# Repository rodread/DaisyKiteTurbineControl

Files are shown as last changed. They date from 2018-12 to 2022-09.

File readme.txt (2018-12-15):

This is the software Rod Read used to control his Daisy Kite turbine on 13/12/2018
The flying rigid rotor kite trubine output over 1kW so this is NO TOY and not for the faint of heart.
Wear a helmet and other protective gear. Stand far clear and not directly downwind or anywhere lashback will be a concern.

You can see just how insane this is here https://youtu.be/UpIECYxP4xc

I was too lazy to reinstate a previous push button for manual overdrive to take twists out... doh
I also aught to go back to having a manual current control for careful slowing down...

As you can see my code is about as far from optimal as a noob like me can mangle

Thanks
rod

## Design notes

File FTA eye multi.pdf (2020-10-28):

384

Ground Station Failure

262

Generation Failure

85
Lifter Fail

Turbine Failure

Transmission Failure

172

56

Material thrown from turbine

871

648

Anchoring error

165

613

75

Backline Fail

Generator Control Compromised

56

689
Generation compromised

248

Efficiency reduced

480

1150

153

Turbine wobble

Transmission compromised

Lift kite position Instability

176

Lift line tension low

Top Lift function fail

Turbine integrity compromised

195

70

147

Backline Safety removed

Rotor stall ability potentially gone

Twisting Lift line

Loss of spreader circular form

Blade integrity compromised

Lift Kite in low turbulent wind

177

105

70

Compression likely on turbine ring

515

Lift Kite in unauthorised airspace

60

Potential for blade strike

Wrong data to controller

Lift kite breakaway

PTO elevation alignment error

56

60

Data recording compromised

Fire risk

14

Ground station position not fixed

285

270

Compression likely on transmission

156

162.5

Thrust transfer to ring compromised

62

546

Battery damage

PTO azimuth alignment error

164

Chain compromised

13

56

32

High degree of twist in turbine form

Transmission centre point disk snags on lift line RPN=32

Ring connector tabs on rim wear out RPN=28

PTO Hub buckles RPN=24

PTO spoke and/or nipple thrown RPN=48

Stub axle thrust bearing circlip dislodged RPN=64

Thrust bearing wears out RPN=36

Stub axle rusts RPN=30

Stub axle weld snaps RPN=16

load cell connection breaks RPN=42 elevaiton arm conncetion breaks RPN=32 motor mount arm welds fail RPN=16 mount or chainring bolt fail RPN=36 magnet too far away RPN=18

Teeth Fatigue wear RPN=30

Chain snaps RPN=14

Sprocket tooth snaps RPN=24 motor/generator overheats from too much current RPN=42 motor/generator bearings wear out RPN=36 motor/genertor cable wiring fault develops RPN=72 elevation adjustment bars fall from nuts and mounts RPN=28 initial tension may not be calibrated at launch RPN=63 control board communicion with load cell system lost RPN=56 load cell cable wiring fault develops RPN=72

bolt unable to provide head movement in frame RPN=42

frame breaks RPN=16

motor alignment too far out RPN=36 head spreader bolt wrong width setting RPN=28

frame buckle RPN=24

stitching failure RPN=32

Sprocket teeth fatigue wear RPN=15

Tracking wheels seize RPN=28 all hub bolts snap or seperate RPN=18

Bridle Point detached from lift line RPN=5

chainring tooth snaps RPN=24

Lift line (Bridle point to back line connection) snap RPN=8

one hub bolt snaps or seperates RPN=32 wheel track blocked with vegitation RPN=42

Back line snap RPN=14

Main Anchor total failure RPN=36

Anchor bends RPN=48

Back anchor missalignment with wind RPN=70

Threaded eye bolt pulled off RPN=8

Back anchor leaves ground RPN=28

VESC not detecting motor/ generator parameters RPN=72

VESC not communicating with control board RPN=63

PTO wheel pulled from stub axle position RPN=48

Lift line snap below top bearing RPN=10

Water ingress into housing RPN=42

failure to read control knob states RPN=72

Transmission Centre point disk line snaps RPN=42 spreader ring rod connector snap RPN=30

spreader ring rod thrown from ring RPN=48 software written by a neewbie RPN=72 control board not communicating with anemometer RPN=42

Top lifting bridle snaps RPN=63 control board not communicating with PC RPN=18

Top Spreader ring centre point disk jams on lift line RPN=21

anemometer failure RPN=28

Fuselage Blade Cuff snap RPN=96

Fuselage body (ring tube) snap RPN=72 wrong speed reading reported from board after voltage change RPN=63 large current spikes on switching RPN=63

Foam blade deterioration RPN=60 electrical power measuring failure RPN=42

large arking current on connection RPN=42

blade cover film deterioration RPN=18

blade cover film detachment RPN=32

Carbon spar tube thrown from blade RPN=32

Through spar retaining line snaps RPN=28

Through spar retaining line thrown RPN=28

Foam Blade Bridle snaps RPN=72

Blade bridle topside spreader thrown RPN=36

Fuselage Bonding Tape tears RPN=36

Carbon spar tube snap RPN=96

Ring tube cuff clasp opens RPN=84

Ring tube cuff tears RPN=54

Foam blade thrown from fuselage RPN=48

Blade position inversion RPN=56

Ring tube cuff line tab tears from cuff RPN=24

Foam blade snap RPN=48

Fuselage looses forward blade connection RPN=42

Fuselage looses trailing blade connection RPN=42

Ring tube snaps RPN=72

Ring tube thrown from turbine RPN=96

Ring Tube Center point disk line snaps RPN=36

Top Spreader ring centre point lines disconnect RPN=24

Turbine ring Center point disk snags on lift line RPN=21 spreader sleeve opens RPN=30 spreader tab disconnects RPN=10 spreader ring rod snap RPN=50

Tether line attachment rings wear or yeild to tension stress RPN=48 Tethers between turbine rings snap RPN=48

Lift line tension too tight inside turbine RPN=87.5

Lift line tension too loose inside turbine RPN=48

Tethers between turbine layers twist RPN=72

Lift line abrasion snap above or in top bearing RPN=72

Lifting bridle detach from small wheel RPN=30

Bearing seizure or high friction RPN=20

Tethers between transmission rings snap RPN=48 | Tethers between transmission rings twist RPN=96

Back anchor connector snap RPN=14

Back line tension too low RPN=40

Transmission ring rod snaps RPN=84 low lift line tension RPN=75

Lift line Length above back line too short RPN=32

Lift line Length above back line too long RPN=56

Transmission ring rod thrown RPN=48

Transmission cuff tears RPN=63

uneven stretch RPN=27

Bridle snap RPN=24

Transmission tabs separate from cuff RPN=14

Lift kite alignment error RPN=40

Skin tear RPN=30

Transmision end connectors separate RPN=28

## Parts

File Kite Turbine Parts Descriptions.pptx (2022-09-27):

## Sub 1kW Kite Turbine Parts

The following parts descriptions are relevant to the <1kW mechanically autonomous Kite Turbines developed at Windswept and Interesting Ltd.
These details are released CC-BY-SA-4.0
TRL ratings are given in the context of a fully autonomous product safe enough to release to the general public as a product.
This turbine design - is not a safe product. You would only replicate this assuming all risk and responsibility

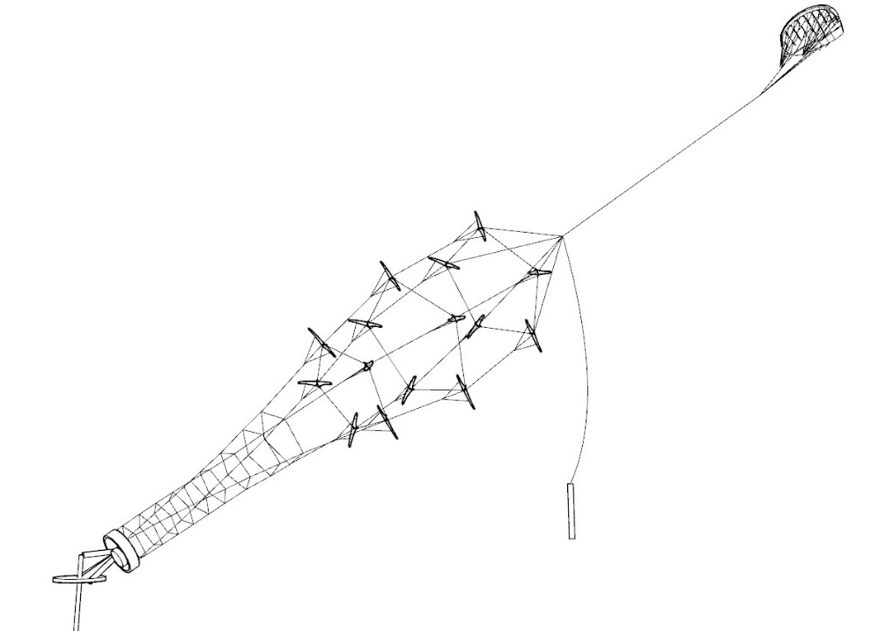
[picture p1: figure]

Lift Kite

Turbine Head

Turbine

Transmission

Backline Handling

Ground Station

## Kite Turbine sub-systems

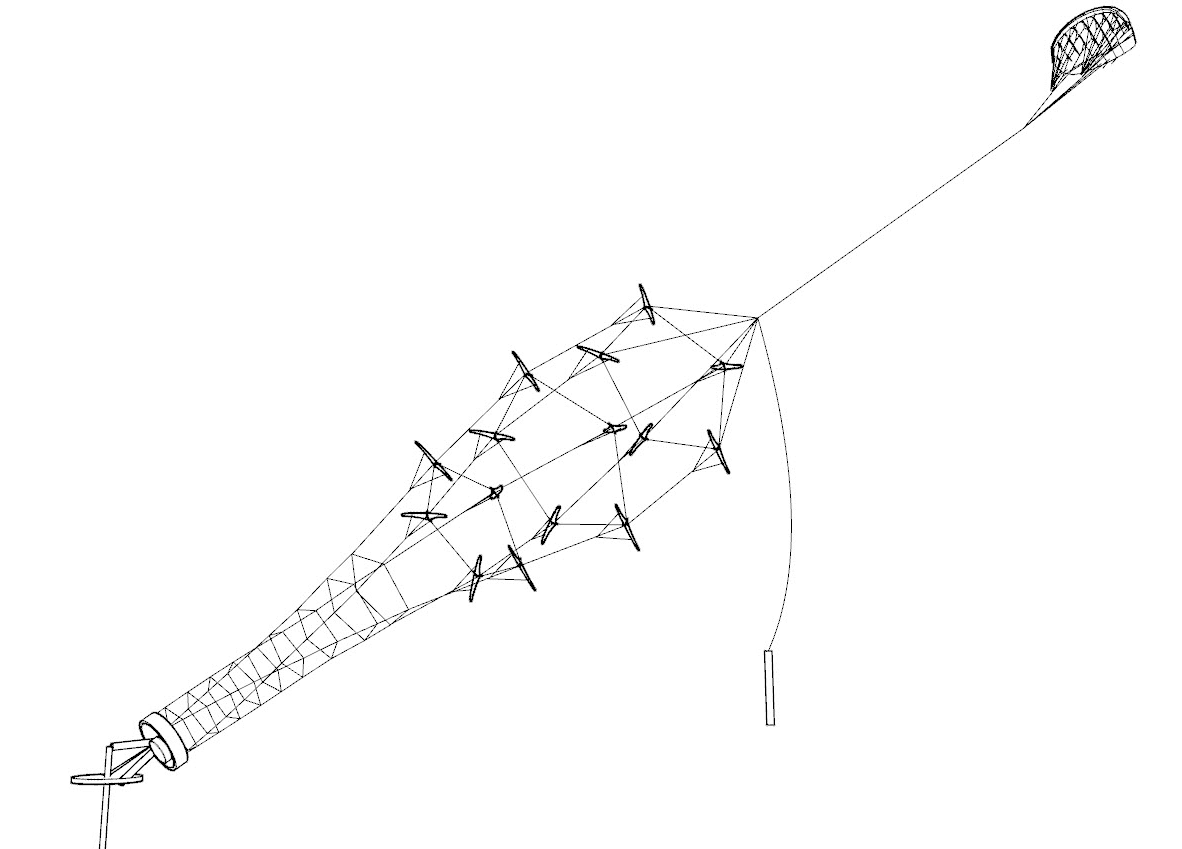
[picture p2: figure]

Lift Kite

Turbine Head

Turbine

Transmission

Backline Handling

Ground Station

## Lift Kite

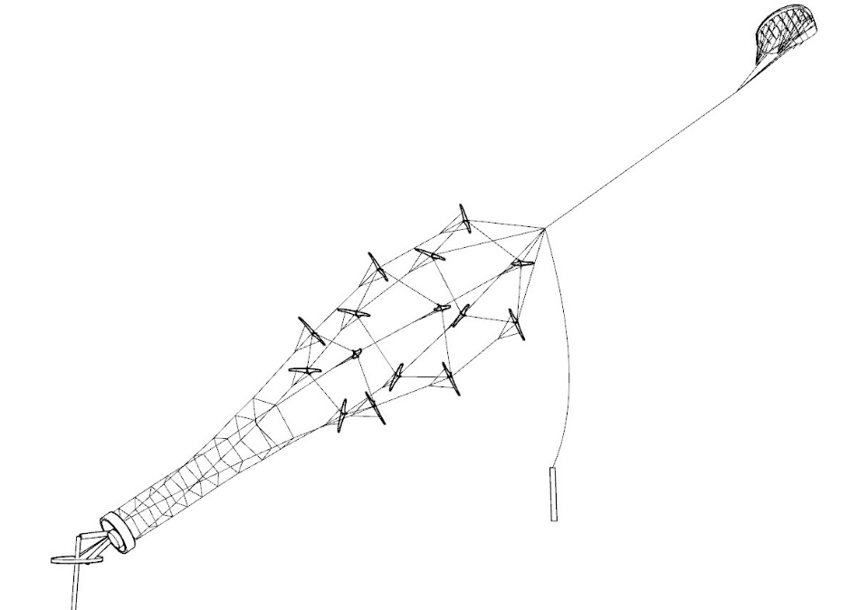
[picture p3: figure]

Lift Kite

Turbine Head

Turbine

Transmission

Ground Station

Backline Handling

State TRL 3 Some basic concept prototypes and models have had an initial field trial Others are still only conceptual. Analogous products exist elsewhere in AWES.

The Lift Kite was always hand launched and landed. - Automating this functionality may help your project.
The Lift kite was mostly a mechanically autonomous HQ KAP lift foil. - Automating this may help your project.
Short tests of battery powered RC servo bridle winding steering systems had run successfully.
You might consider a flight controller, onboard charging, communications, rtk GPS and novel steering.
Steering has run on basic IMU sensing with bluetooth control - You will want to update steering algorithms, Add field wifi and operational mode awareness for reliability and safety.
Lift Kite position was occasionally limited within the prevailing wind with two additional lightweight steering anchor lines tied to steering bridles - You may want to address methods of full azimuth operation and bank angle control to enable operation throughout the wind window and in changing wind conditions.

Windswept & Interesting Ltd, Emsket, Nesbister, Shetland ZE2 9LJ Registered Limited Company SC439249

## Turbine Head

State TRL 3
The turbine head has been constructed from adapted skate wheel and axle configurations. No smarts included.
The system has run both ways - with simple through axles holding the turbine tip whilst the rim held the top lift line steady and with the turbine on the rim and the axle steadied by the lift and backline. This second configuration is preferred.
No attitude, speed, power, monitoring, communications, control or autonomous connection has yet been functionally implemented

You may want to augment a turbine head to be capable of communicating rtk gps position and line tension data to aid ground station alignment and backline handling. The turbine head is attached and detached from the lift-line/ back-line whilst in the launch and land stages.

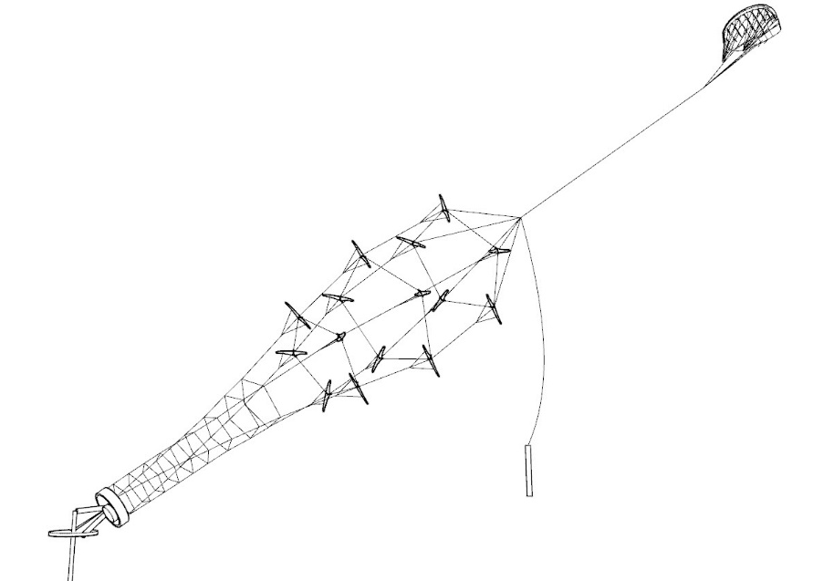
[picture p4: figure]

Turbine Head

Lift Kite

Turbine

Transmission

Ground Station

Backline Handling

## Backline Handling

State TRL 3
The Backline Handling has been limited to manual handling operations to date.
The backline has been a partially bungeed line, anchored to hold the turbine head lower and downwind.
On occasion we used spread twin lines from the ground to the turbine head & lift line connection point - to limit azimuth drift under an unsteady lifter.
A straight line ground “horsetrack” backline anchor system has been trialled to allow azimuth tracking whilst keeping backline tension.
The backline has been tested with bungee to remove the potential for slack to wrap around in the case of torque transfer to the lift line.
The backline has been manually tested for turbine stalling. In turbine stalling the backline is pulled around the field to pull the turbine head to a position 90 deg to the inflow of wind… Thus stalling the turbine.

Lift Kite

Turbine Head

Transmission

Ground Station

Turbine

Backline Handling

## Turbine

State TRL 4
Several “blade” kites set around a rigidised ring form a turbine rotor.
Our early turbines mostly exploited the cheap and easy fix nature of ram air kites attached to varied forms of ring support system.
A shift in design to rigidised foam profile wings resulted in the best AWES Power/Weight test efficiency to date.
A first description of the turbine system performance was achieved through a PhD collaboration with University of Strathclyde.

Turbine can be modularly constructed to be able to be flown alone or stacked together.
A turbine rotor can connect to another lower turbine rotor, or to the transmission.

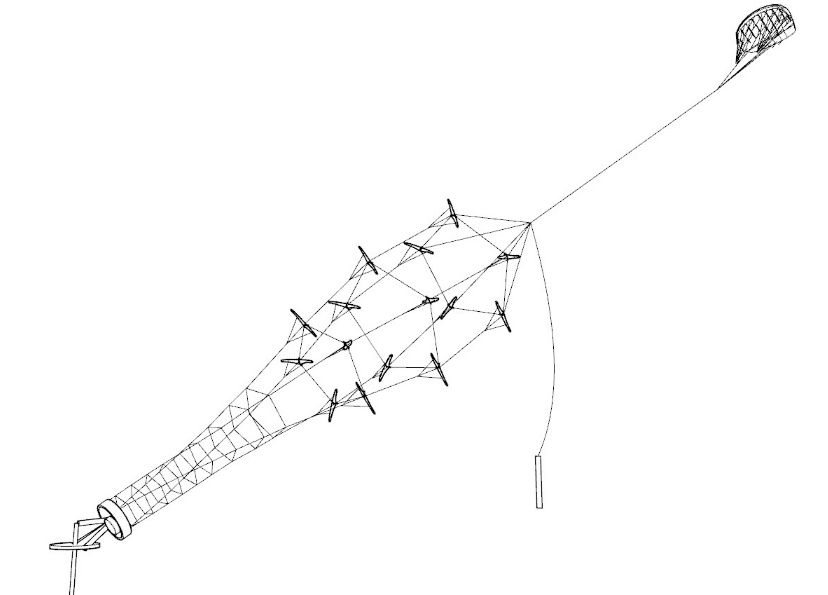
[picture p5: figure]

Lift Kite

Turbine Head

Turbine

Transmission

Ground Station

Backline Handling

## Transmission

State TRL 4
The unique dynamic properties of Tensile Rotary Power Transmission (TRPT) were described in Oliver Tulloch’s PhD.
TRPT is a new class of Airborne Wind Energy power transmission.
Several variations of transmission have been tested and characterised at W&I.
W&I prefer the more dynamic polygon to polygon TRPT in preference to rod to crossed rod style TRPT (see tuddel power someawe.org) due to handling and efficiency benefits

TRPT can be modularly constructed.
Transmission line tabs attach transmission lines to the polygon nodes.

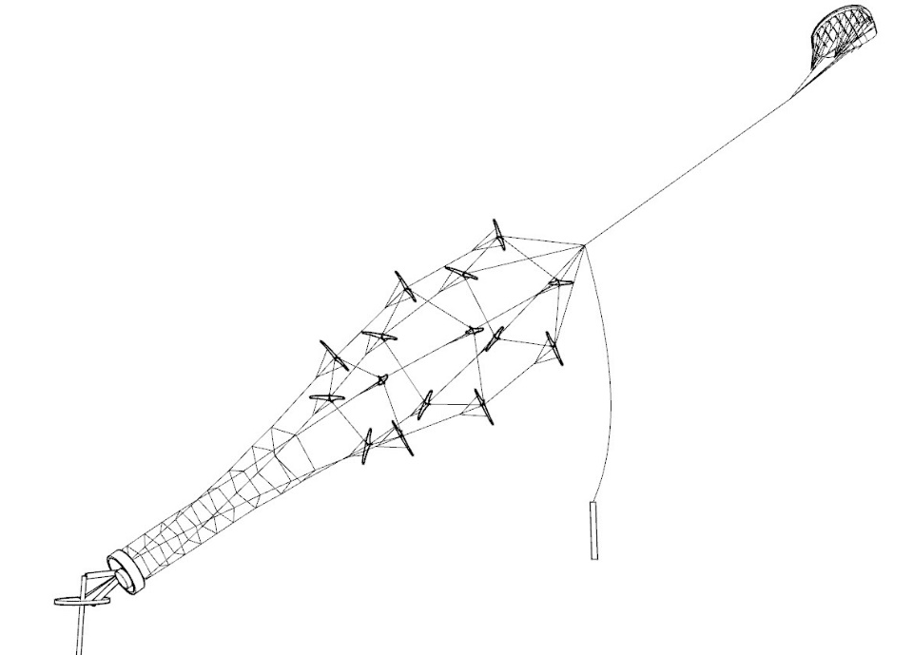
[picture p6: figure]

Lift Kite

Turbine Head

Turbine

Transmission

Ground Station

Backline Handling

## Ground Station

State TRL 3
The Ground Stations had passive azimuth alignment with elevation tracking predominantly being set pre-flight, manually. It is best to set this firmly before launch as the dynamic interaction of generation can easily impact axial alignment. This assumes you will hold the turbine head in a relatively fixed position.
The generation system used a VESC for torque control using FOC on a 500W rated BLDC motor. Regen went into 2 x e-bike batteries
Control commands came from a basic human interface combined in an algorithm with data from anemometer, onboard tension sensing and the speed controller.
Make sure your ground station is securely fixed to a very oversized anchor system.

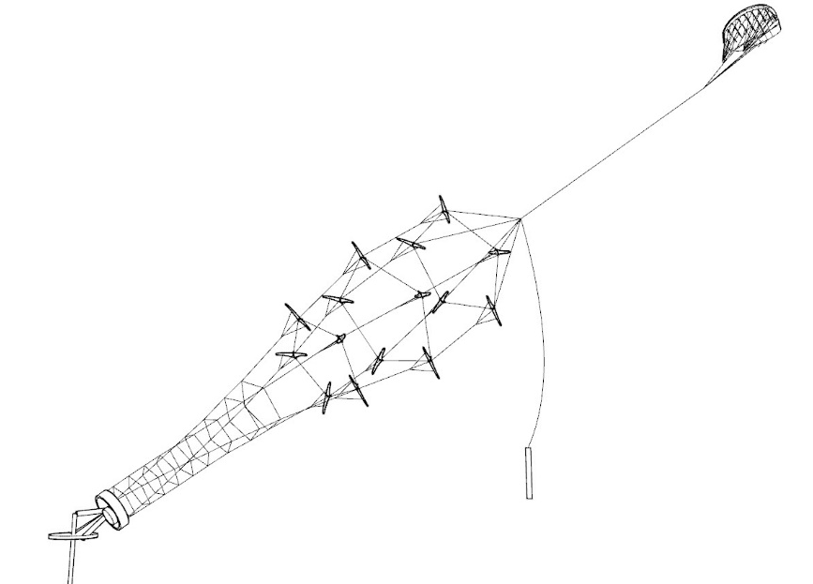
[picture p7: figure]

Lift Kite

Turbine Head

Turbine

Transmission

Ground Station

Backline Handling

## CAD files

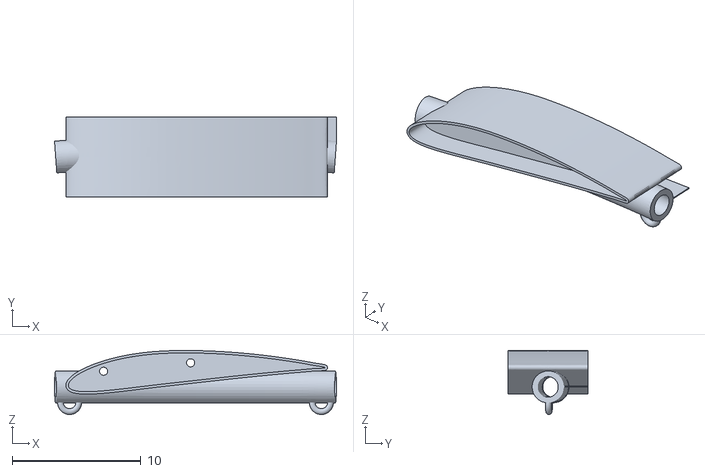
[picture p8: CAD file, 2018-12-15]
Cuff-thinner-foamCORE.stl
21.9 x 6.20 x 4.98

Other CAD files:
foamCOREdaisyDRIVERroot4.3dm

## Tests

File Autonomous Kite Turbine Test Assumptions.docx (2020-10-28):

# Autonomous kite network systems

# Assumptions on Proposals

### Proposals

The following models describe 4 Kite Turbine system configurations. The systems require increasing levels of development and autonomy for safe operation.

We describe 5 levels of autonomy (end of this document) which Kite Turbines and Lifting Kite Networks will employ. The simplest, level 1, mechanical autonomy with human interaction, has been well tested.

### Background

Windswept and Interesting developed a series of mechanically autonomous kite turbines. University of Strathclyde analysed the performance of 9 rotor configurations, over 120 hours of flight & 45 test flights. Over the test period the efficiency and power output of our turbines increased 10X. (Power harvesting factor ζ is now around 3.) Our Kite Turbines have the safest configuration & the best AWES Power/Weight & Power/Wing Area. This is the only AWES with continuous rotary output.

A lightweight tensile design, exploiting network deployment, makes Kite Turbines very scalable.

Kite Turbine power coefficients have stayed constant with stacking. We predict the following performance benefits with network scaling … decreased drag, maximised utility of harvested airspace, robust operation, mass production with unitised wing components, modular reconfiguration while flying & in deployment, networked form safety and more.

This is the first predictive LCOE analysis by W&I on our systems at scales over 10kW. W&I have no prior experience of manufacturing Kite Turbine products at this scale. There will be a lot of scope for production efficiency as compared to the costings shared here.

### Scale choices

The 4 systems presented are

### Model Proposal 1 10kW Kite Turbine with single lifter Level 3 Autonomy

### Model Proposal 2 50kW Kite Turbine with single lifter Level 4 Autonomy

### Model Proposal 3 1.8MW 18 lift kite network x 100kW kite turbines Level 4 Autonomy

### Model Proposal 4 10MW Single Kite Turbine Network no lifter Level 5 Autonomy

Models 1 & 2 represent the lower end scale of viable turbine size for their autonomy level. Larger, more profitable systems at the same level of autonomy would be possible and likely desirable.

### Model Proposal 1

## 10kW Kite Turbine with single lifter Level 3 Autonomy

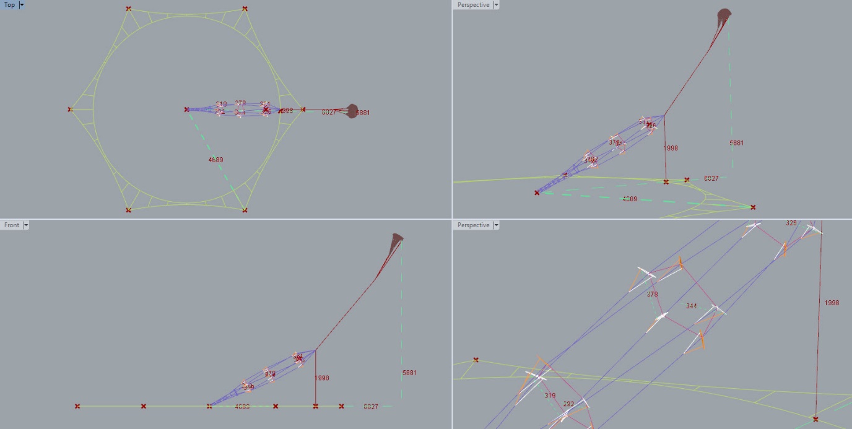
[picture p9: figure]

Turbine format

Turbine Rotor Layers 3

Blades per layer 5

Blade Construction 2 Carbon Spar coated foam

Rated wind speed 10m/s

Power coefficient 0.27

Tip Speed Ratio 6.5

Rotor radius 3.2m

Blade length 1.3m

Rotor speed 196 rpm

Stack elevation angle 28 deg

Supporting hoops 1 for top lift, 2 below for TRPT transition

Thrust bearing top spreader hub for lift line 2 x 25mm min

In blade lighting only for display-oriented systems

Blade control and automation requirements none at Level 3 autonomy

Moulded fuselage without controls or communications, but with payload ports available for monitoring, power gen or alternate benefits.

Lightning protection via landing if a significant risk is forecast

TRPT format

Hexagonal form with moulded knuckles and 8mmx10mm bar

Hex Diameter .8m

Torque 487 Nm

Running setpoint Tension/Torque 6

Sections 6 - 10 minimum with .59m spacing

Lines 5 x 600kg breaking 2mm dyneema

Radial centre lines to loose fit hoop guide for lift line on every ~3rd

Line fairing none yet

Lift kite format

Static KAP foil equivalent area 30m²

Altitude <60m for easy compliance

Bridle point control and comms unit with onboard power gen @~100W

Lighting aimed at skin & horizon

Required Lift line tension 1820N

Lift line length 45m Max with hoist line pulley and backline/liftline method

Ground Station Format

Main anchor geology dependant, to resist >9000N vertical

Lateral support plate 40cm dia with 6 x 30cm deep anchors, hub interface and cable routing

Single stub axle truck hub for azimuth bearing with through axle power cable access

Crane frame box section main body format with azimuth drive

Tilting head set with elevation adjusting linear actuator from frame and headset tension measurement at head tilt bearing mounts.

Small hoisting tension winch aligned behind head to hollow stub axle

Gearbox attached to head set over hollow section stub axle with rearward inline 10kW generator

PTO wheel .8m Diameter rim with ~20cm hub axial length

Thrust bearing at kite end of stub axle set with locking nuts and cotter pin.

360 Backline Format

Short driven turret carriage with dual winch on tensioned rope ring

Backline winch 1 for hoisting turbine toward lift line pulley

Backline winch 2 for lift kite launcher and recovery into short line choke turret

Backline tensioned rope ring frame anchors x 6 @ 47m radius >8000N vertical

General

Total airborne mass <6kg

Total ground-station mass <25kg

Serviceable Lifetime Ground Station 10 years

Retail Cost of 10kW Ground Station and turbine set £15.5k

Service Lifetime of Rotor Set 1.5 Years

Cost of replacement Rotor Set £1250

O&M cost £1100/year

### Model Proposal 2

## 50kW Kite Turbine with single lifter Level 4 Autonomy

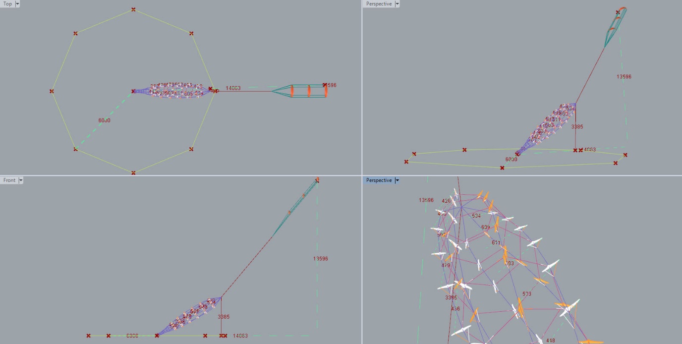
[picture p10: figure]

Turbine format

Turbine Rotor Layers 6

Blades per layer 7

Monocoque with ground fed power or ducted turbine onboard power

Rated wind speed 10m/s

Power coefficient 0.28

Tip Speed Ratio 6.6

Rotor radius 5.5m

Blade length 1.7m

Rotor speed 114 rpm

Stack elevation angle 30 deg

Supporting hoops 1 for top lift, 2 below for TRPT transition

Thrust bearing top spreader hub for lift line 2 x ~35mm

Blade to blade expansion twin winching control and bank adjust automation requirements

Meshed communications on each blade

Blade illumination

Lightning protection via landing if a significant risk is forecast

TRPT format

Single septagonal form, bonded ~18mm carbon tube

Septagon Diameter 1.8m

Torque 4172 Nm

Running setpoint Tension/Torque 5

Sections 6 minimum with 1.2m spacing

Lines 7 x 4000kg breaking 6mm dyneema

Radial centre lines to loose fit hoop guide for lift line on every ~3rd

Line fairing

Lift kite format

Stacked LEI to equivalent single area 250m²

Altitude ~135m

Primary bridle point control and comms unit with onboard power gen @~500W

Lighting aimed at skin & horizon

Required lift line tension <15kN depending on turbine autonomous lift steering balance

Backline control for stalled turbine and lift fail recovery

Ground Station Format

Main anchor geology dependant, to resist >60000N vertical

Lateral support plate 50cm dia with 6 x 50cm deep anchors, hub interface and cable routing

Single stub axle truck hub for azimuth bearing with through axle power cable access

Crane frame box section main body format with azimuth drive

Tilting head set with elevation adjusting linear actuator from frame and headset tension measurement at head tilt bearing mounts

Hoisting tension winch aligned behind head to hollow stub axle

Gearbox attached to head set over hollow section stub axle with rearward inline 50kW generator

PTO wheel 1.8m Diameter rim with ~35cm hub axial length

Thrust bearing at kite end of stub axle set with locking nuts and cotter pin.

8 Point Backline Format

Three LEI Stack release turrets working radially from 8 anchor 60m radius octagonal line.

Backline winch 1 for hoisting turbine toward lift line pulley

Backline winch 2 for lift kite launcher and recovery into short line choke turret with arm assist turrets further out radially.

Backline tensioned rope ring frame anchors x 8 @ 64m radius >40kN vertical

General

Total airborne mass ~25kg

Total ground-station mass ~100kg

Retail Cost of 50kW Ground Station and turbine set £51.3k

Service Lifetime of Rotor Set 2 Years - Ground Station 12 years

Retail Cost of replacement Rotor Set £11950

O&M cost £2400/year

### Model Proposal 3

## 1.8MW 18 lift kite network x 100kW kite turbines Level 4 Autonomy

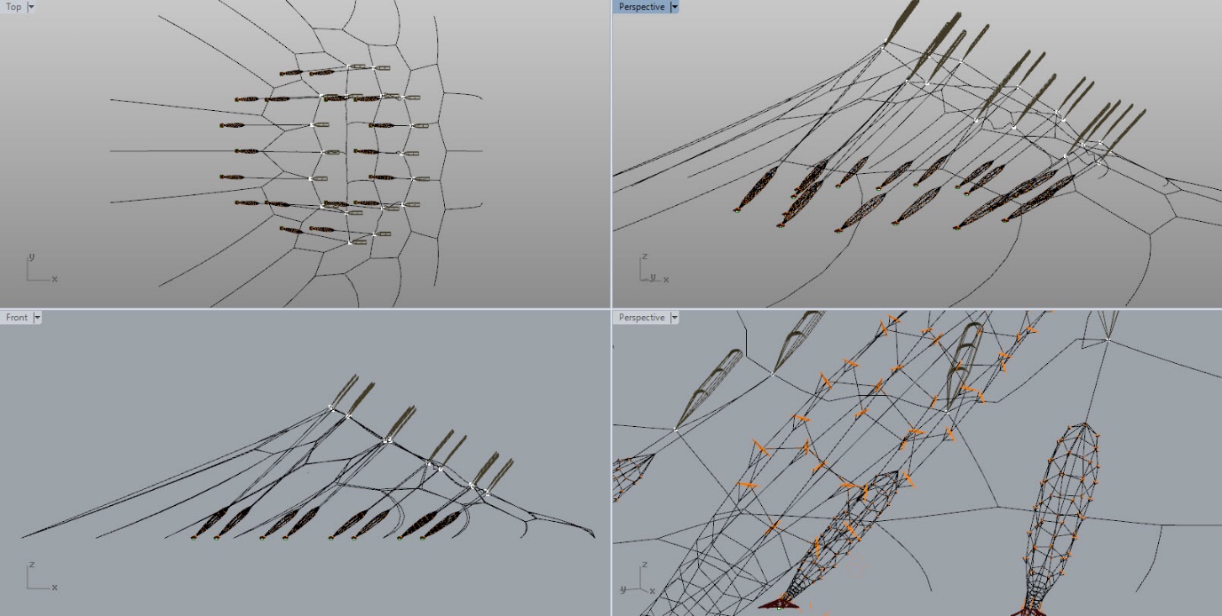
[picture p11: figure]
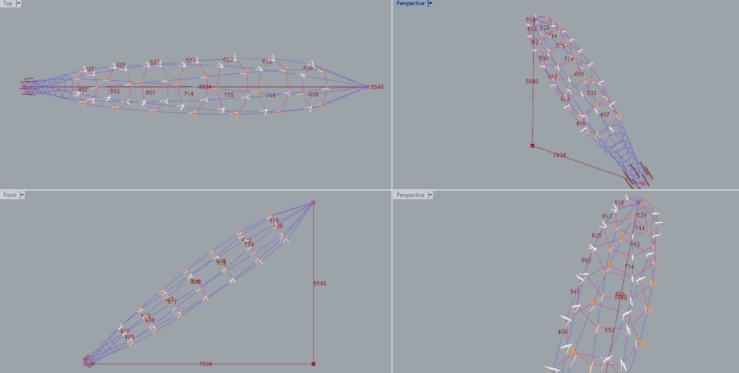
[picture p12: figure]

18x Turbine format

18 Top netted lifters each with a 100kW Turbine

Turbine Rotor Layers 7

Blades per layer 7

Blade Construction Carbon Monocoque with ducted turbines on top layer

Rated wind speed 11m/s

Power coefficient 0.28

Tip Speed Ratio 6.6

Rotor radius 6.6m

Blade length 1.7m

Rotor speed 104 rpm

Stack elevation angle 35 deg

Supporting hoops 1 for top lift, 2 below for TRPT transition

Thrust bearing top spreader hub for lift line 2 x ~45mm

Blade to blade expansion twin winching control and bank adjust automation requirements

Meshed communications on each blade

Illumination over top via networked wiring

Lightning protection via outer net lines and landing if a significant risk is forecast

18x TRPT format

Single septagonal form, bonded ~30mm dia carbon tube

Septagon Diameter ~3m

Torque 9140 Nm

Running setpoint Tension/Torque 5

Sections 6 minimum with ~1.8m spacing

Lines 7 x 9000kg breaking 12mm dyneema

Radial centre lines to loose fit hoop guide for lift line on every ~3rd

Line fairing

18x Lift kite format

Stacked LEI to equivalent single area ~400m²

Altitude ~135m back - ~250m front

Primary bridle point control and comms unit with network power

Lighting aimed at skin & horizon

Required lift line tension <32kN depending on turbine autonomous lift steering balance

Whole net control for stalling turbines and lift fail recovery

18x Ground Station Format

Main anchor geology dependant, to resist >130000N vertical

Lateral support plate ~60cm dia with 6 radial anchors, hub interface and cable routing

Single stub axle truck hub for azimuth bearing with through axle power cable access

Crane frame box section main body format with azimuth drive

Tilting head set with elevation adjusting linear actuator from frame and headset tension measurement at head tilt bearing mounts

Hoisting tension winch aligned behind head to hollow stub axle

Gearbox attached to head set over hollow section stub axle with rearward inline 100kW generator

PTO wheel ~3m Diameter rim with ~45cm hub axial length

Thrust bearing at kite end of stub axle set with locking nuts and cotter pin.

Extra kite handling, stability, meteorology, safety, containment, ground layout, ++ undisclosed as yet

General

Total airborne mass ~40kgx18

Retail Cost of 18x100kW Ground Station and turbine set £1.19M

Service Lifetime of Rotor Set 2 Years - Ground Station 12 years

Retail Cost of replacement Rotor Set £593695

O&M cost £28000/year

### Model Proposal 4

## 10MW Single Kite Turbine Network no lifter Level 5 Autonomy

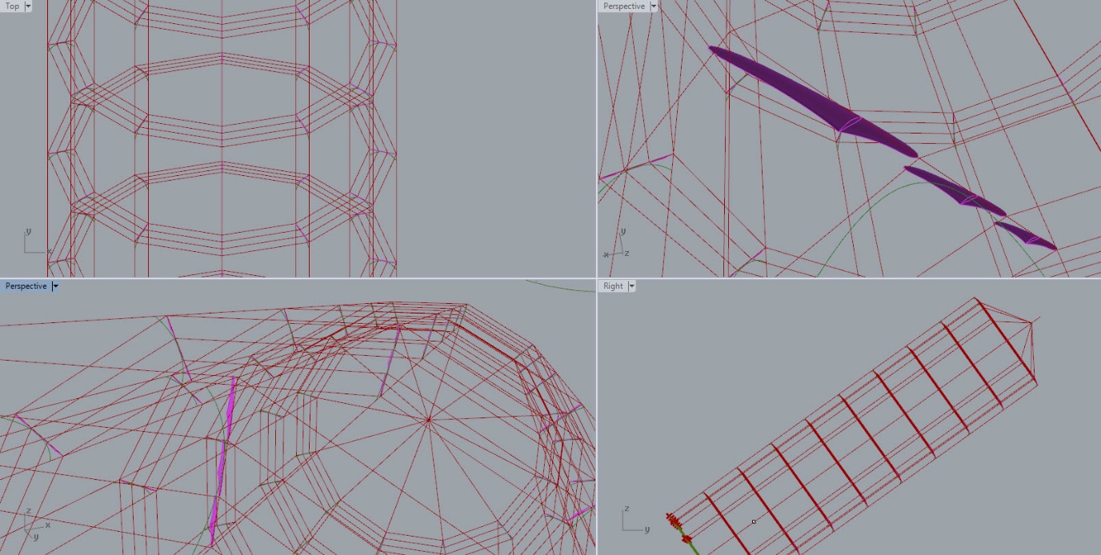
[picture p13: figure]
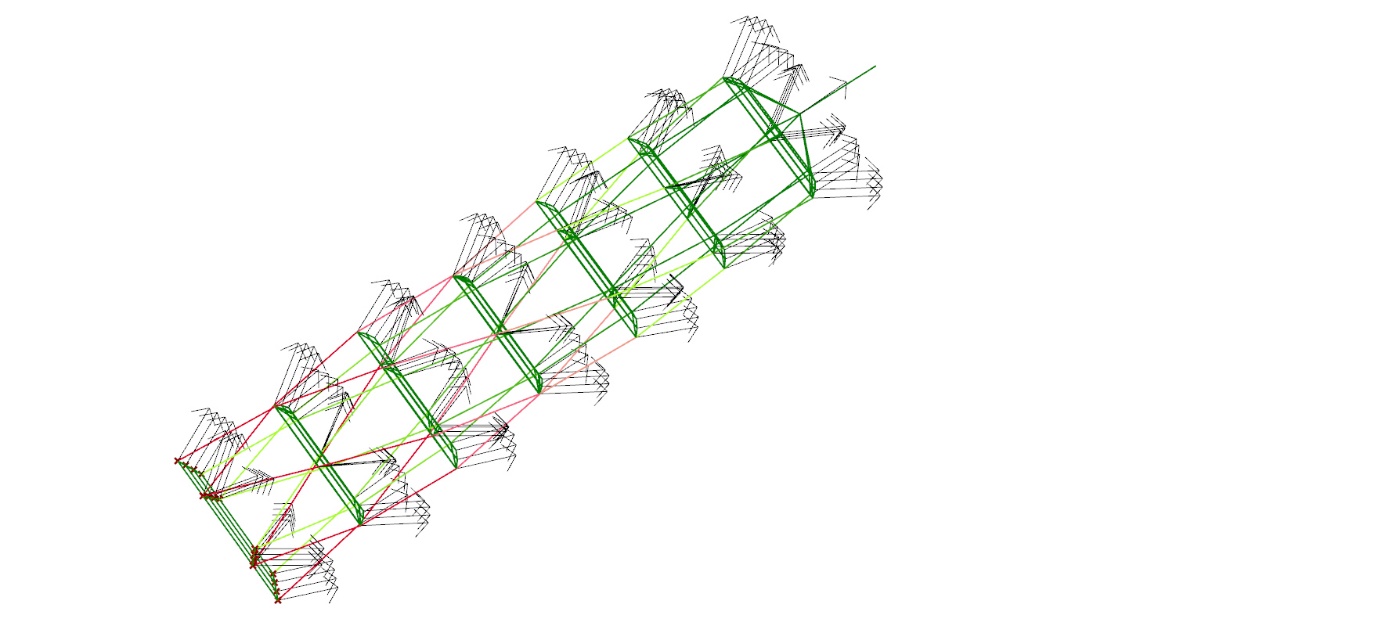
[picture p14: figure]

Figures for this model must be considered as more provisional than for the previous models

Turbine format

12 blade rings with 3 rings concentrically per layer over 10 layers

Carbon mould monocoque wing and fuselage with hatch for control and winching service

Top layer with ducted turbine

Rated wind speed 11m/s

Power coefficient 0.3

Tip Speed Ratio 6.9

Rotor radius 50m

Blade length 4.9(x3)m

Rotor speed 14 rpm

Stack elevation angle 35 deg

No TRPT - Turbine direct to PTO

Thrust bearing top spreader hub for lift line 2 x 45mm min

Blade to blade expansion twin winching control and bank adjust automation requirements

Meshed communications on each blade

Illumination over top layer via Top Layer RAT

Lightning protection via landing if a significant risk is forecast & sacrificial centre line

Drone interface and servicing to pilot kit

Pilot kite format

Stacked LEI to equivalent single area ~200m²

Altitude ~150m - ~200m

Primary bridle point control pod with onboard ram

Lighting aimed at skin & horizon

Required lift line tension - none

Ground Station Format

Large groundworks with truncated hemisphere range of frame support using rail to rail and active tensile anchor ring system.

12 arm servicing for modular connection and store handling of blade sets

Centre line winch

Optimal gear and generation configuration still under investigation

PTO wheel ~40+m Diameter rim

Extra kite handling, stability, meteorology, safety, containment, ground layout, ++ undisclosed as yet

General

Total airborne mass ~350kg

Retail Cost of 10MW Ground Station and turbine set ~£8.9M

Service Lifetime of Rotor Set 4 Years - Ground Station 16 years

Retail Cost of replacement Rotor Set £337k

O&M cost £50k/year

Kite Turbine Networks autonomy class definitions

(All classes include generation control enhancements based on ground station configuration & monitoring.)

Level 1 Mechanical Autonomy suitable for <1kW to 5kW range - Already developed

Azimuth alignment of turbine via Standard KAP style lift kite without needing control pod.

Lifted Autogyro turbine power smoothing and overspeed protections potential from twist tip leach gust spilling or spanwise compression. Reflex foil smoothing may also be applicable.

Turbine elevation height set via backline anchor. Backline anchor can either be set to run on a tensile ring rope & trolley anchoring set or just planted or set on a horsetrack range.

Manual launching and landing procedures.

Further improvements on basic mechanical autonomy performance are being developed.

Further improvements on autonomous generation and ground station performance are being developed.

Level 2 Mechanical Autonomy + semi automation of single line lift. Turbine in 5kW to 10kW range - partly developed at W&I requiring <6 months to complete. Single prototype development budget ~£45k. 2x external AWES developers consulting sought.

Azimuth alignment of turbine via KAP style lift kite using bridle point control pod, onboard power from 50W. Control pod communicates intention and state over standard comms networks.

Launch to be semi-autonomous. Kite is filled and held by winch at ground with control turned on before launch. Still using winching by hand to set lift line and backline height. Turbine elevation height set via backline anchor. Backline anchor can either be set to run on a tensile ring rope & trolley anchoring set or just planted or set on a horsetrack range.

Lifter can decide to force a landing to side depending on states.

Lifted Autogyro turbine power smoothing and overspeed protections potential from twist tip leach gust spilling, or spanwise compression.

Further Lift Kite Network smoothing, pattern following and robustness investigations can be performed at this level of lift autonomy.

Level 3 = Level 2+ automation of single lift kite operation + automation of turbine by hoist deployment 10kW to 50kW range - New ground-station & back line turret construction and testing required <1 year of development from a team of 3 full time engineers. Single prototype development budget ~£155k Cooperation with existing AWES kite system developers would help.

Azimuth alignment of turbine via larger rigidised style lift kite >45m2 using bridle point control pod, onboard power ~200W. Control pod communicates intention and state with a linked phone.

Lifter launch, flight and recovery to be autonomous. Initialisation and coupling to be manual. Kite is filled and active when held winched into the backline turret. Launch command is checked manually. Array of cameras available to assist with remote launch decision.

Two winches, one for lift kite line and backline height, the other for hoisting and lowering the kite turbine. Backline anchor turret carriage mounted to run on a tensile ring rope. System can recover turbine to ground and lifter to turret. Turbine is laid on ground via the winching recovery and held down by the lift line. Full detail undisclosed awaiting patenting.

Lifted Autogyro turbine power smoothing and overspeed protections potential from twist tip leach gust spilling, bank stall, or spanwise compression. Potential to add active flap tuning with power either from network or from turbine head gen set or from small RAT on wing.

Lift Kite Networks will be able to dynamically alter group pattern for optimal top net tension and inflation.

Level 4 = Level 3 + PTO aligned, retracting frame supports for ground hold, launch release and recovery of rotors and TRPT. Rotor expansion blade to blade winching. >50kW range. >1 year development from a team of 5 full time engineers. Single prototype development budget ~£400k Cooperation with existing AWES teams and OEM’s very desirable.

Relatively less lifter requirement with lift component control on blades.

Live rescaling rotor diameter.

State analysis allows turbine prelaunch condition to be approved autonomously.

Full detail undisclosed awaiting patenting.

Level 5 = Level 4 + PTO aligned frame automatically reconfigures and reattaches TRPT + rotors as needed. Individual blades to have NLMPC onboard flight controls, swarm network. Higher accuracy infield positioning and meteorology. 100kW + range. Development time 2+ years for a team of 10 full time engineers. Single prototype development budget £2+M. Cooperations with existing AWES kite system teams & supply chain.

Lift kite network only for field alignment and spacing. Lift comes from rotor with ground powered launch and land.

Full detail undisclosed awaiting patenting.

All systems have potential to incorporate autonomous video / light display modes in rotor blades.

Windswept and Interesting Ltd http://windswept-and-interesting.co.uk 2 Lovers Loan, Lerwick, Shetland UK ZE10BA 07899057227 Registered in Scotland SC439249

2 Lovers Loan, Lerwick, Shetland UK ZE10BA rod.read@windswept-and-interesting.co.uk 00 44 7899 057227 Windswept and Interesting Ltd

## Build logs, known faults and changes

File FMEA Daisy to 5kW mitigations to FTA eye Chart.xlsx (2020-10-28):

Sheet: possible errors reference sheet
 |  |  |  | possible failure modes- in operation phase | component | Functions | intended | human error | not intended | command fault
Subsystem | Components | Subcomponents | 1 | deflation | lift kite | lifter | 1 |  | 1
lifter | kite |  | 2 | too gusty | wind | natural |  |  | 1 |  | (carbon rod bend and joint in carbontubes is called sleved )
line network/ Rotary system | rings structure | carbon fiber tubes covered in dacron. | 3 | ? | ice | natural |  |  | 1
 | tether | dyneema | 4 | ? | rain | natural |  |  | 1
 | blades | blue foam/polystyrene | 5 | breaking of carbon fiber tubes | ring structure | rotary system | 1 |  | 1
Ground Station and PTO | Bike wheel | chain drive, nuts ,boltsand bearings etc. | 6 | split in dacron | ring structure | rotary system | 1 | 1 | 1 |  | prevent the guide line from twisting | back anchor
 | electronic components | Cables and wires etc | 7 | split in dyneema | tether |  | 1 |  | 1
 | sensors |  | 8 | breaking of polystyrene | blades | rotary system | 1 |  | 1
 | generator |  | 9 | not grounded properly | back anchor | support structure | 1 | 1 | 1
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

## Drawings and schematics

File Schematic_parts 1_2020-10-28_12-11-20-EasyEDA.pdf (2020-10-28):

H1
H2

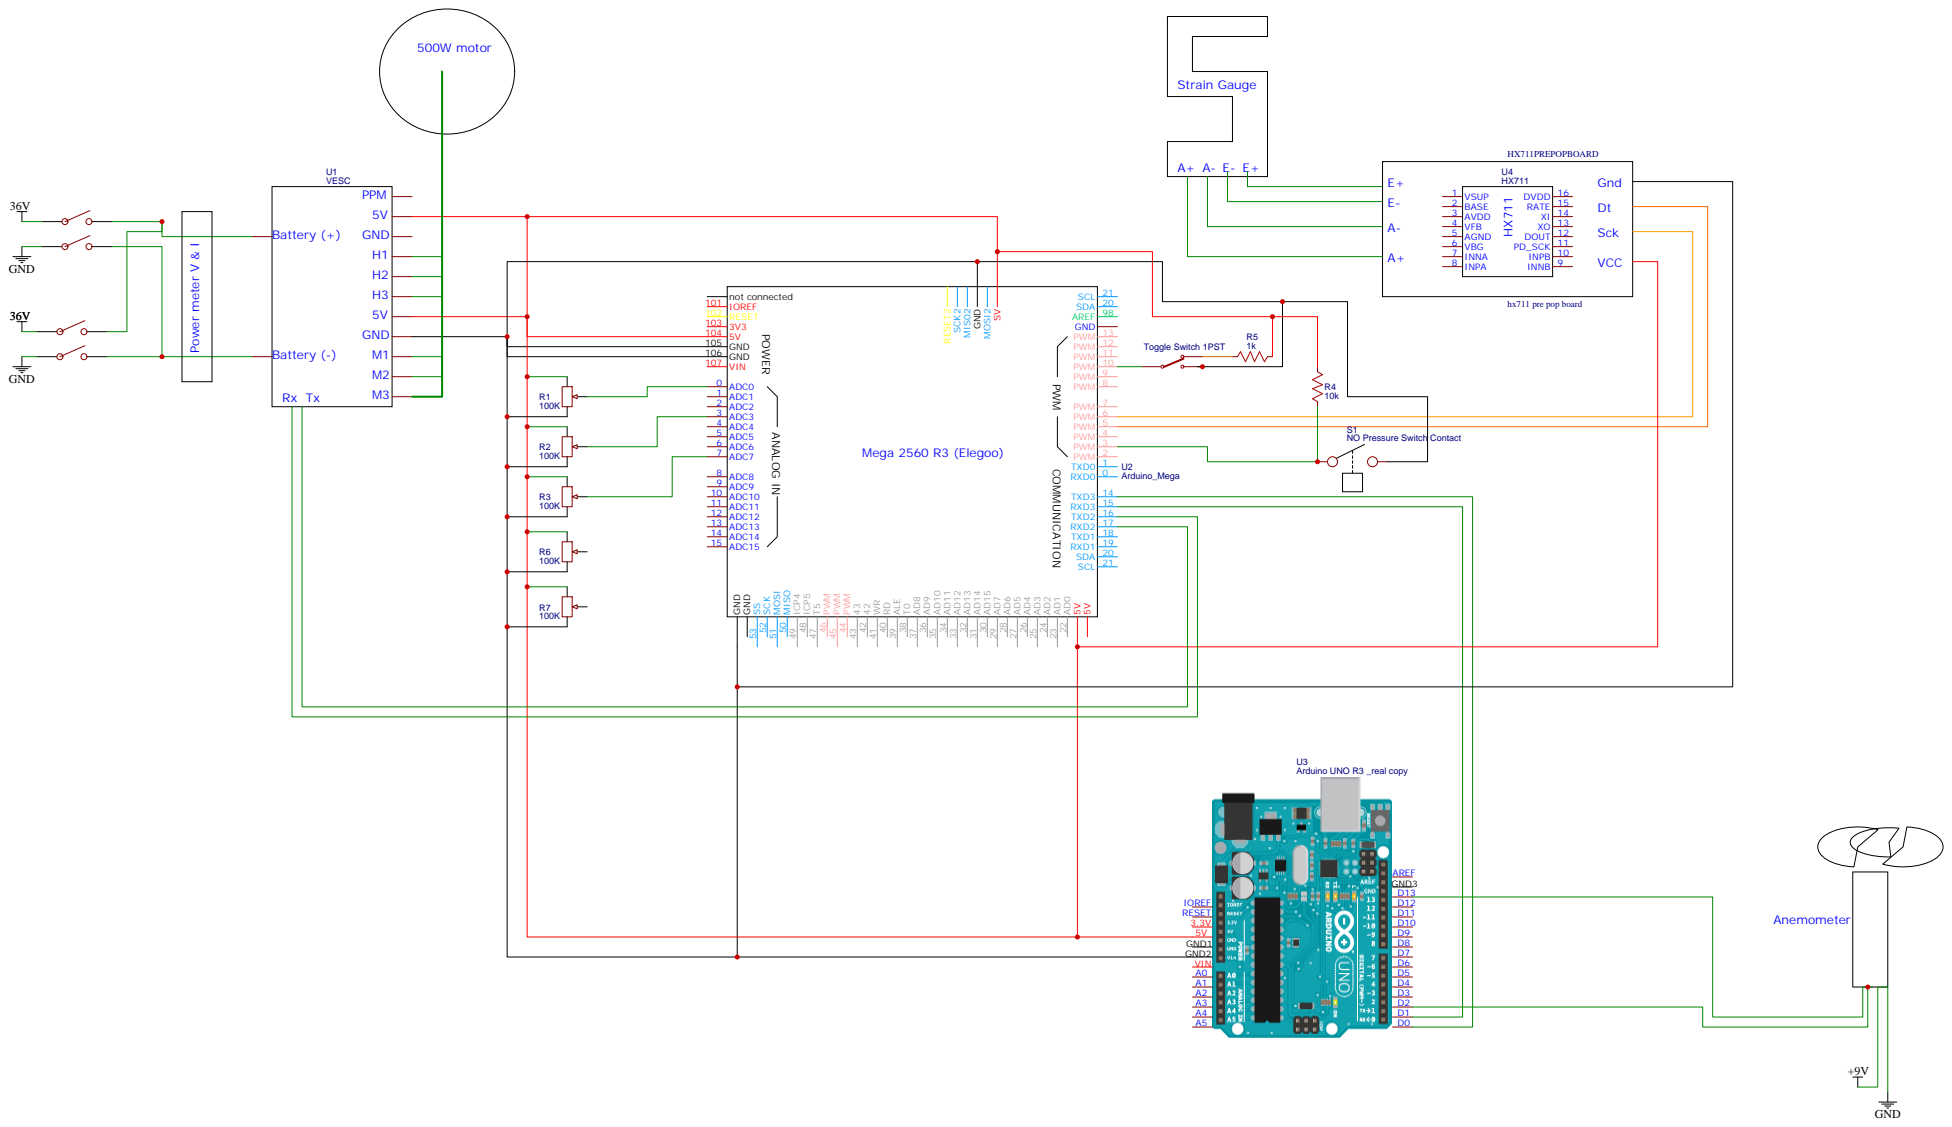
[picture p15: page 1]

NO Pressure Switch Contact

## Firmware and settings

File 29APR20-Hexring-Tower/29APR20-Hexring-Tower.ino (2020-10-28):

/*
Rod Reads Ground Station control software for Rotary Kite Network Airborne Wind Energy by Windswept and Interesting Ltd

Looking to up the speed of the main loop() by removing print parts etc into object oriented...
still need to do to this and change emergency overdrive into an interrupt and flag change.

A max amount of regen current is decided by dial, 
then the amount actually demanded is decided via addition of 3 calculated quotient parts 
Speed trend, TSR and TTR

(TSR)Tip Speed Ratio dial set point will be compared to rotor speed and wind speed data.

Similarly there's a (TTR) Tension Torque Ratio setpoint using tension readings and regen current data

VESC speed trend data will also be taken into account


Problem with VESC interface software   ---   only works on old VESC firmware ~V 3.8   Latest VESC fw > v 6

  Original VESC UART interface work :Copyright 2016 Tobias Sachs Tobias.Sachs@onlinehome.de

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
 created by:  Tobias Sachs 
 messed with by ROD READ for kite ground station controller
 Name:        
 Created:   22/09/2016  messed with again until now
 Author:    TS then Rod R

  by David A. Mellis  <dam@mellis.org>
  modified 9 Apr 2012
  by Tom Igoe
  http://www.arduino.cc/en/Tutorial/Smoothing


//has emergency drive forward override This is going up to 8 amps from 2 - 3 dec 2019  ---  MAKES no difference to VESC SPeed though

//You have to configure the VESC to APP "UART" and set the baudrate to  115200 
// 
//You have to uncommend the line "#define USE_PATCHED_VESC_FW_2_18" in the file VescUartControl.h
// I got rid of the getLimits parts
//
//Could do with getting a more relevant comms set to and from the VESC... I think there are other VESC commands available
//A firmware upgrade for the VESC is available now too...

 Setup your scale and start the sketch WITHOUT a weight on the scale
 Once readings are displayed place the weight on the scale
 Press +/- or a/z to adjust the calibration_factor until the output readings match the known weight
 Arduino pin 6 -> HX711 CLK
 Arduino pin 5 -> HX711 DOUT
 Arduino pin 5V -> HX711 VCC
 Arduino pin GND -> HX711 GND 
*/

#include "VescUartControl.h"

VescController Vesc1;

struct bldcMeasure measuredVESC1;

uint16_t counts = 0;  //unsure... something to do with VESC comms

#include "HX711.h"

float calibration_factor = 10; // this calibration factor is adjusted according to my load cell
float tensionunits;              // approx = grams

float TSRsetpoint;
//float TSRactual;
float TSRaveraged;
float TSRQuota =0.1;

float TTRsetpoint;
float TTRactual;
float TTRMaxValue = 20.0;
float TTRQuota =0.1;

float tipspeed;
float windspeed = 2.0;

float SpeedTrendQuota =0.1;

HX711 scale(5, 6);


const int EMbuttonPin = 8;     // the pushbutton pin for emergency drive forward       DOUBLE CHECK YOU HAVE THIS WIRED
int EM_FW_buttonState = 0;         // variable for reading the pushbutton status

const int StartButtonPin = 2;     // the pushbutton pin for Brake at start
int StartButtonState = 0;         // variable for reading the Brake at start pushbutton status

int sensorPin1 = A0;    // select the input pin for brakecurrent ramp up average compare setpoint
float sensorValue1TSR = 5.0;  // variable to store the value coming from the sensor

int sensorPin2 = A5;    // select the input pin for the brakecurrent ramp up rate
float sensorValue2TTR = 5.0;  // variable to store the value coming from the sensor

int sensorPin7 = A7;    // select the input pin for the brakecurrent max level
float sensorValue7 = 0.1;  // variable to store the value coming from the sensor

float maxbrakecurrent = 0.5; // A limit value for the maximum allowable current
int StartBrakeCurrent = 16.0; // The initial hold brake current before release to generate up from 14


const int numReadings = 4;  //size of array for smoothing rpm readings 
const int numReadingsB = 15;  //size of long array for smoothing rpm readings 

const int numReadings2 = 4;  //size of array for smoothing tension readings 
const int numReadings3 = 3;  //size of array for smoothing windspeed readings 

float readings[numReadings];      // the rpm array
int readIndex = 0;              // the index of the current rpm reading
float total = 0.0;                  // the running total rpm
float averageSpd1 = 0.0;                // the average rpm

float readingsB[numReadingsB];      // the Long rpm array
int readIndexB = 0;              // the index of the current rpm reading
float totalB = 0.0;                  // the running total rpm
float averageSpdLong = 0.0;                // the average rpm

float readings2[numReadings2];      // the tension array
int readIndex2 = 0;              // the index of the current tension reading
float total2 = 0.0;                  // the running total tension
float averageTens = 0.0;                // the average tension

float readings3[numReadings3];      // the winspeed array
int readIndex3 = 0;              // the index of the current windspeed reading
float total3 = 0.0;                  // the running total windspeed
float averageWind = 0.0;                // the average windpseed

#define DEBUG
unsigned long count;   //not needed? Maybe to do with VESC comms
unsigned long count2;  //not needed? Maybe to do with VESC comms

float turnrate;          //erpm converted into approx rpm below
float RAD_Per_Sec;       //and then probably miles off a radpersec value

float brakeCurrent;      //desired braking level at moment

float TSRstepUP = 0.02;   //amount higher we raise brake current per itteration if TSR is too high
float TSRstepDOWN = 0.2;   //amount higher we lower brake current per itteration if TSR is too low

float TTRstepUP = 0.02;   //amount higher we raise brake current per itteration if TTR is too high
float TTRstepDOWN = 0.2;   //amount higher we lower brake current per itteration if TTR is too low


String inputString = "";         // a String to hold incoming wind data on serial 3
bool stringComplete = false;  // whether the wind data string is complete



void setup()
{
  Serial.setTimeout(5);
  
  pinMode(StartButtonPin, INPUT);  // initialize the pushbutton pin as an input: 
  
  Serial.begin(115200); //begin Serial Console
  delay(100);
  Serial2.begin(115200); //begin VESC Serial Console
  delay(200);
  Serial3.begin(115200); //begin wind data Serial port
  delay(100);

  // reserve 200 bytes for the inputString: wind data
  inputString.reserve(200);

  Vesc1.begin(&Serial2);
  Vesc1.UartSetCurrent(0.0);
  Vesc1.UartSetCurrentBrake(0.02);
  delay(50);
 
  scale.tare();  //Reset the scale to 0

    delay(30);

  long zero_factor = scale.read_average(5); //Get a baseline reading
  Serial.print("Zero factor: "); //This can be used to remove the need to tare the scale. Useful in permanent scale projects.
  Serial.println(zero_factor);
  
  delay(30);


  scale.set_scale(calibration_factor); //Adjust to this calibration factor

  
  delay(30);
  
  for (int thisReading = 0; thisReading < numReadings; thisReading++) {
                          readings[thisReading] = 0;} //clear rpm smooth array 
   delay(10); 
  
  for (int thisReadingB = 0; thisReadingB < numReadingsB; thisReadingB++) {
                          readingsB[thisReadingB] = 0;} //clear longer rpm smooth array 
   delay(10); 
   
  for (int thisReading2 = 0; thisReading2 < numReadings2; thisReading2++) {
                          readings2[thisReading2] = 0;} //clear tension smooth array   
   delay(10);
  for (int thisReading3 = 0; thisReading3 < numReadings3; thisReading3++) {
                          readings3[thisReading3] = 0;} //clear the windspeed smooth array    
    delay(50);

}

void loop()
{
 
EM_FW_buttonState = digitalRead(EMbuttonPin); // read the state of the emergency forward pushbutton value:      

  // check if the emergency drive forward pushbutton is pressed. If pressed the buttonState is LOW: end of loop routine (long loop = really hard to read program sorry)
if (EM_FW_buttonState == HIGH) 
  { 

  
  StartButtonState = digitalRead(StartButtonPin); // read the state of the Brake at start pushbutton value:
  // check if the StartBrakeCurrent pushbutton is pressed. If it is, the buttonState is HIGH:
 if (StartButtonState == HIGH) 
    {
     Vesc1.UartSetCurrentBrake(StartBrakeCurrent);   //It's startup routine ... brakes high... Not time for spin up & regen yet
     windspeed = Serial3.parseFloat();     //Lets look at wind first Then get load cell readings

    tensionunits = scale.get_units(2), 10; // these roughly = gramms equivalent 2000 ~=2kg pull

    if (tensionunits < 0.0)
    {
      tensionunits = (tensionunits * -1.0);
    }    
              //Serial.print("erpm_VESC1: "); Serial.print(",");
              Serial.print("Startup Brake on ");Serial.print(",");
              Serial.print(" rpm = ");Serial.print(",");
              Serial.print(turnrate);Serial.print(",");
              Serial.print(" Wind_tip_TSR_TSRset ");Serial.print(",");
              Serial.print(windspeed);Serial.print(",");
              Serial.print(tipspeed);Serial.print(",");
              Serial.print(TSRaveraged);Serial.print(",");
              Serial.print(TSRsetpoint);Serial.print(",");
              Serial.print(" Ten-g_genA_TTR_TTRset ");Serial.print(",");
              Serial.print(tensionunits);Serial.print(",");
              Serial.print(StartBrakeCurrent);Serial.print(",");
              Serial.print(TTRactual);Serial.print(",");
              Serial.print(TTRsetpoint);Serial.print(",");
              Serial.print(" Amax ");Serial.print(",");
              Serial.print(maxbrakecurrent);Serial.print(",");
              Serial.print(" SpdQ TTRQ TSRQ ");Serial.print(",");
              Serial.print(SpeedTrendQuota);Serial.print(",");
              Serial.print(TTRQuota);Serial.print(",");
              Serial.println(TSRQuota);Serial.print(",");
            delay (300);
           loop (); 
            }
else
{
    // OK we're out of startup, let's roll with it.   Lets get wind speed data first.  Then lets get load cell readings.
 
    windspeed = Serial3.parseFloat();
 
              // Lets find the average windspeed
               total3 = total3 - readings3[readIndex3];// subtract the last windpseed reading:
                readings3[readIndex3] = windspeed;// read windspeed from this program:
                total3 = total3 + readings3[readIndex3];// add the reading to the total:
                readIndex3 = readIndex3 + 1;// advance to the next position in the array:
              
                if (readIndex3 >= numReadings3) { // if we're at the end of the array...wrap around to the beginning:
                   readIndex3 = 0;             }
                   delay(1);        // delay in between reads for stability
                   
                averageWind = (total3/numReadings3); // calculate a recent average windspeed     
     
    scale.set_scale(calibration_factor); //Adjust to this calibration factor
    tensionunits = scale.get_units(), 10; // these roughly = gramms equivalent 2000 ~=2kg pull
    if (tensionunits < 0.0)
    {
      tensionunits = (tensionunits * -1.0);
    }
 
              // Lets find the average tension
               total2 = total2 - readings2[readIndex2];// subtract the last tension reading:
                readings2[readIndex2] = tensionunits;// read tension from this program:
                total2 = total2 + readings2[readIndex2];// add the reading to the total:
                readIndex2 = readIndex2 + 1;// advance to the next position in the array:
              
                if (readIndex2 >= numReadings2) { // if we're at the end of the array...wrap around to the beginning:
                   readIndex2 = 0;             }
                   delay(1);        // delay in between reads for stability
                   
                averageTens = (total2/numReadings2); // calculate a recent averageSpd1 tension      
    

  //not worrying about including tension calibration now lets get knob set points

          sensorValue1TSR = analogRead(sensorPin1);   // read the value from rotary knob sensor 1:
          TSRsetpoint = (map (sensorValue1TSR, 0,1023,250,550)) / 100.0; //TSR setpoint map limit TSR min to 2.5 top possible setpoint value to ~5.5, 
                                                                       
          delay (2);
          sensorValue2TTR = analogRead(sensorPin2);   // read the value from the sensor 2:
          TTRsetpoint = (map (sensorValue2TTR, 0,1023,10,2000)) / 100.0; // TTR (kg pull / amps braking) want it to be ~ around ~ 0.7 I guess, max here is 20
                                                                       
          delay (2);
          sensorValue7 = analogRead(sensorPin7);   // read the value from the sensor 7: for max current
          maxbrakecurrent = (map (sensorValue7, 0,1023,1,1300)) / 100.0; // dial on A7 limiting max current from 0.1 to 13.0
          delay (2);
        


          
          if (Vesc1.UartGetValue(measuredVESC1))
              {              
              turnrate = (measuredVESC1.rpm / (920000*3.8)); //20khz x 46 poles  (23 pairs) why 3.8? -fudge factor to get the rpm roughly calibrated (odd because gear ratio is 47:22)
 
 
              // Lets find the short average turn rate
               total = total - readings[readIndex];// subtract the last rpm reading:
                readings[readIndex] = turnrate;// read rpm from this program:
                total = total + readings[readIndex];// add the reading to the total:
                readIndex = readIndex + 1;// advance to the next position in the array:
                if (readIndex >= numReadings) { // if we're at the end of the array...wrap around to the beginning:
                   readIndex = 0;             }
                   delay(1);        // delay in between reads for stability
                averageSpd1 = (total/numReadings); // calculate a recent average turnrate 

              // and a longer average turn rate
               totalB = totalB - readingsB[readIndexB];// subtract the last rpm reading:
                readingsB[readIndexB] = turnrate;// read rpm from this program:
                totalB = totalB + readingsB[readIndexB];// add the reading to the total:
                readIndexB = readIndexB + 1;// advance to the next position in the array:
                if (readIndexB >= numReadingsB) { // if we're at the end of the array...wrap around to the beginning:
                   readIndexB = 0;             }
                   delay(1);        // delay in between reads for stability
                averageSpdLong = (totalB/numReadingsB); // calculate a longer recent average turnrate
                                              
              //Tip Speed Ratio
              RAD_Per_Sec = (averageSpd1*0.104719755) ;
              tipspeed = (RAD_Per_Sec * 2.25); //rotor tip outer radius 2.25m 
              TSRaveraged = (tipspeed/averageWind); //tipspeed uses rpm average ... averageWind is windspeed av
              
                
              TTRactual = ((averageTens/1000.0) / brakeCurrent);
              if (TTRactual > TTRMaxValue){
                TTRactual = TTRMaxValue; }
                
  
                      
                      //slow states check
                      if (averageSpd1 < 65.0)
                      {
                           if (averageTens > 50000){    //Worried this could be runaway overtwist because turn rate is low tension is high
                              Vesc1.UartSetCurrentBrake(0.0);  //No braking
                              Vesc1.UartSetCurrent(8.0);    //unwind for a while
                              Serial.println("Emergency forward software");    // WARNING THIS MAY KICKSTART A ROTOR IN READY TO GEN Condition with strong lift tension
                              delay(1200);  
                              brakeCurrent = 0.02;
                              Vesc1.UartSetCurrent(0.0);
                              Vesc1.UartSetCurrentBrake(0.02);  //Start from very low again
                            }
                            else{                        
                      Vesc1.UartSetCurrentBrake(0.02);  //turn rate is too slow now lets not try braking
                      brakeCurrent = 0.02;
                          Serial.print("Too Slow 4 gen");Serial.print(",");
                          Serial.print(" rpm = ");Serial.print(",");
                          Serial.print(turnrate);Serial.print(",");
                          Serial.print(" Wind_tip_TSR_TSRset ");Serial.print(",");
                          Serial.print(windspeed);Serial.print(",");
                          Serial.print(tipspeed);Serial.print(",");
                          Serial.print(TSRaveraged);Serial.print(",");
                          Serial.print(TSRsetpoint);Serial.print(",");
                          Serial.print(" Ten-g_genA_TTR_TTRset ");Serial.print(",");
                          Serial.print(tensionunits);Serial.print(",");
                          Serial.print(brakeCurrent);Serial.print(",");
                          Serial.print(TTRactual);Serial.print(",");
                          Serial.print(TTRsetpoint);Serial.print(",");
                          Serial.print(" Amax ");Serial.print(",");
                          Serial.print(maxbrakecurrent);Serial.print(",");
                          Serial.print(" SpdQ TTRQ TSRQ ");Serial.print(",");
                          Serial.print(SpeedTrendQuota);Serial.print(",");
                          Serial.print(TTRQuota);Serial.print(",");
                          Serial.println(TSRQuota);Serial.print(",");
                          delay(1);  
                            }
                          }
              else
              //fast enough              
              { 
                                          
                      if (averageTens < 1800){  //a 1.8kg minimum pull on the line (because readings are gippy but the linkage is gippy at best)
                          brakeCurrent = 0.1;
                          Vesc1.UartSetCurrentBrake(brakeCurrent);
                          Serial.print("Weak lift tension");Serial.print(",");
                          Serial.print(" rpm = ");Serial.print(",");
                          Serial.print(turnrate);Serial.print(",");
                          Serial.print(" Wind_tip_TSR_TSRset ");Serial.print(",");
                          Serial.print(windspeed);Serial.print(",");
                          Serial.print(tipspeed);Serial.print(",");
                          Serial.print(TSRaveraged);Serial.print(",");
                          Serial.print(TSRsetpoint);Serial.print(",");
                          Serial.print(" Ten-g_genA_TTR_TTRset ");Serial.print(",");
                          Serial.print(tensionunits);Serial.print(",");
                          Serial.print(brakeCurrent);Serial.print(",");
                          Serial.print(TTRactual);Serial.print(",");
                          Serial.print(TTRsetpoint);Serial.print(",");
                          Serial.print(" Amax ");Serial.print(",");
                          Serial.print(maxbrakecurrent);Serial.print(",");
                          Serial.print(" SpdQ TTRQ TSRQ ");Serial.print(",");
                          Serial.print(SpeedTrendQuota);Serial.print(",");
                          Serial.print(TTRQuota);Serial.print(",");
                          Serial.println(TSRQuota);Serial.print(",");
                        }



                      
                      if (averageTens > 1500){
                        //TSR first
                        if (TSRaveraged > (TSRsetpoint * 1.1)){
                          TSRQuota = (TSRQuota + 0.01);}
                        if (TSRaveraged < (TSRsetpoint * 0.85)){
                          TSRQuota = (TSRQuota - 0.02);}
                          if (TSRQuota > 1.0){
                            TSRQuota = 1.0;}
                          if (TSRQuota <0.1){
                            TSRQuota = 0.1;}


                          
                          //TTR next
                        if (TTRactual > (TTRsetpoint * 1.1)){
                          TTRQuota = (TTRQuota + 0.01);}
                        if (TTRactual < (TTRsetpoint * 0.85)){
                         TTRQuota = (TTRQuota - 0.04);}
                          if (TTRQuota > 1.0){
                            TTRQuota = 1.0;}
                          if (TTRQuota <0.1){
                            TTRQuota = 0.1;}


                        if (averageSpd1 > (averageSpdLong * 1.1)){
                          SpeedTrendQuota = (SpeedTrendQuota + 0.01);}
                        if (averageSpd1 < (averageSpdLong * 0.85)){
                          SpeedTrendQuota = (SpeedTrendQuota - 0.04);}
                          if (SpeedTrendQuota > 1.0){
                            SpeedTrendQuota = 1.0;}
                          if (SpeedTrendQuota <0.1){
                            SpeedTrendQuota = 0.1;}


                            


 brakeCurrent =    maxbrakecurrent * ((SpeedTrendQuota*0.3)+(TTRQuota*0.2)+(TSRQuota*0.5));                  //ammount contribution of max brake allowed from each component .3x spd trend + .2x TTR + .5x TSR



                       if (brakeCurrent > maxbrakecurrent){
                         brakeCurrent = maxbrakecurrent;}
                       if (brakeCurrent < 0.15){
                         brakeCurrent = 0.15;}
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

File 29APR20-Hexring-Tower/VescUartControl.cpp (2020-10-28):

/*
	Copyright 2015 - 2016 Andreas Chaitidis Andreas.Chaitidis@gmail.com
	Copyright 2016 Tobias Sachs Tobias.Sachs@onlinehome.de

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
    You should have received a copy of the GNU General Public License
    along with this program.  If not, see <http://www.gnu.org/licenses/>.
*/

/*
 created by:	Andreas Chaitidis
 derived by:	Tobias Sachs
 Name:			VescUartControl.cpp
 Created:		22/09/2016
 Author:		TS
*/

//#if defined(__arm__) && (defined(__MK20DX128__) || defined(__MK20DX256__))
// ******************************************************************************
// Teensy 3.0 implementation, using Programmable Delay Block
// ******************************************************************************

#include "VescUartControl.h" //include the declaration for this class
#include "buffer.h"
#include "crc.h"

/** Default constructor, uses default serial port.
 * @see serial
 */
VescController::VescController()
{
  _Serial = NULL;
}

/** Class destructor to free up memory */
VescController::~VescController()
{
	// Do nothing
}

/** Specific address constructor.
 * @param serialIn defines the serial used by the instance of the class
 */
void VescController::begin(HardwareSerial *serialIn)
{
  _Serial =serialIn;
  _Serial->begin(115200);
}

/** Setpoint for the current controller
 * @param current defines the driving current the controller should set
 */
void VescController::UartSetCurrent(float current)
{
	int32_t index = 0;
	uint8_t payload[5];
		
	payload[index++] = COMM_SET_CURRENT ;
	buffer_append_int32(payload, (int32_t)(current * 1000), &index);
	PackSendPayload(payload, 5);
}

/** Setpoint for the current controller
 * @param current defines the braking current the controller should set
 */
void VescController::UartSetCurrentBrake(float brakeCurrent)
{
	int32_t index = 0;
	uint8_t payload[5];

	payload[index++] = COMM_SET_CURRENT_BRAKE;
	buffer_append_int32(payload, (int32_t)(brakeCurrent * 1000), &index);
	PackSendPayload(payload, 5);
}

int16_t VescController::PackSendPayload(uint8_t* payload, int lenPay)
{
	uint16_t crcPayload = crc16(payload, lenPay);
	int16_t count = 0; //TODO original int
	uint8_t messageSend[256];
	if (lenPay <= 256)
	{
		messageSend[count++] = 2;
		messageSend[count++] = lenPay;
	}
	else
	{
		messageSend[count++] = 3;
		messageSend[count++] = (uint8_t)(lenPay >> 8);
		messageSend[count++] = (uint8_t)(lenPay & 0xFF);
	}
	memcpy(&messageSend[count], payload, lenPay);

	count += lenPay;
	messageSend[count++] = (uint8_t)(crcPayload >> 8);
	messageSend[count++] = (uint8_t)(crcPayload & 0xFF);
	messageSend[count++] = 3;
	messageSend[count] = (uint8_t)NULL;
	//Sending package
	_Serial->write(messageSend, count);
	_Serial->flush();
	//serial.flush() needed to wait until serial send buffer is written

	//Returns number of send bytes
	return count;
}

bool VescController::UartGetValue(bldcMeasure& values)
{
	uint8_t command[1] = { COMM_GET_VALUES };
	uint8_t payload[256];
	PackSendPayload(command, 1);
	delay(100); //needed, otherwise data is not read it is needed in addition to _Serial.flush()
	int lenPayload = ReceiveUartMessage(payload);

	if (lenPayload > 55) {
		bool read = ProcessReadPacket(payload, values, lenPayload); //returns true if sucessful
		return read;
	}
	else
	{
		return false;
	}
}

#if defined (USE_PATCHED_VESC_FW_2_18)
bool VescController::UartGetLimits(bldcLimits& limits)
{
	uint8_t command[1] = { COMM_GET_LIMITS };
	uint8_t payload[256];
	PackSendPayload(command, 1);
	delay(100); //needed, otherwise data is not read it is needed in addition to _Serial.flush()
	int lenPayload = ReceiveUartMessage(payload);

	if (lenPayload > 56)
	{
		bool read = ProcessReadPacketLimits(payload, limits, lenPayload); //returns true if sucessful
		return read;
	}
	else
	{
		return false;
	}
}
#endif //if defined (USE_PATCHED_VESC_FW_2_18)

int16_t VescController::ReceiveUartMessage(uint8_t* payloadReceived)
{
	//Messages <= 255 start with 2. 2nd byte is length
	//Messages >255 start with 3. 2nd and 3rd byte is length combined with 1st >>8 and then &0xFF
	 
	uint16_t counter = 0; //TODO original uint8_t
	int16_t endMessage = 256; //TODO original int
	bool messageRead = false;
	uint8_t messageReceived[256];
	int16_t lenPayload = 0; //TODO original int
	while (_Serial->available())
	{
		messageReceived[counter++] = _Serial->read();

		if (counter == 2)
		{//case if state of 'counter' with last read 1

			switch (messageReceived[0])
			{
			case 2:
				lenPayload = messageReceived[1];
				endMessage = lenPayload + 5; //Payload size + 2 for size + 3 for CRC and End.
				break;
			case 3:
				//ToDo: Add Message Handling > 255 (starting with 3)
				break;
			default:
				break;
			}

		}

		if (counter >= sizeof(messageReceived))
		{
			break;
		}

		if (counter == endMessage && messageReceived[endMessage - 1] == 3)
		{//+1: Because of counter++ state of 'counter' with last read = "endMessage"
			messageReceived[endMessage] = 0;		
			messageRead = true;
			break; //Exit if end of message is reached, even if there is still more data in buffer. 
		}
	}

	bool unpacked = false;
	if (messageRead)
	{
		unpacked = UnpackPayload(messageReceived, endMessage, payloadReceived, lenPayload);
	}
	if (unpacked)
	{
		return lenPayload; //Message was read

	}
	else
	{
		return 0; //No Message Read
	}
}

bool VescController::UnpackPayload(uint8_t* message, int lenMes, uint8_t* payload, int lenPay)
{
	uint16_t crcMessage = 0;
	uint16_t crcPayload = 0;
	//Rebuild src:
	crcMessage = message[lenMes - 3] << 8;
	crcMessage &= 0xFF00;
	crcMessage += message[lenMes - 2];

	//Extract payload:
	memcpy(payload, &message[2], message[1]);

	crcPayload = crc16(payload, message[1]);

	if (crcPayload == crcMessage)
	{
		return true;
	}
	else
	{
		return false;
	}
}
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

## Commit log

2020-10-28 Add files via upload
    Circuit layout for the control system
2020-10-28 Add files via upload
    FMEA from FTA on system for the next stage prototype
    [FMEA Daisy to 5kW mitigations to FTA eye Chart.xlsx]
2020-10-28 Add files via upload
    Some pics from 17th May 2019 of single rotor build and some test results analysis including stacked dual rotor data
    [17May2019 srm conditioned for gh2.xlsx]
2020-10-28 Add files via upload
    Ground station controller software
2022-09-27 fuselage and wings in igs

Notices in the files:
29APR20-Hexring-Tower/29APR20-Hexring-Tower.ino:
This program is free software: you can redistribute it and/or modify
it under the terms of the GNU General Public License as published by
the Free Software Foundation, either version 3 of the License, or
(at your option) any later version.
